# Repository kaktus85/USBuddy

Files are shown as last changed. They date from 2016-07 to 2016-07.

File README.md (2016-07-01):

# USBuddy
This repository contains all the available documentation and source files for USBuddy USB development tool project.
- A copy of this is also available on Google Drive: https://drive.google.com/drive/folders/0B7G3xJXZNLUpYzR0Vlo4bV9fNGM
- An article about this project is here: http://kaktuscircuits.blogspot.cz/2016/03/usbuddy.html and on Hackaday.io: https://hackaday.io/project/10372-usbuddy
- USBuddy can be purchased through Tindie: https://www.tindie.com/products/Kaktus/usbuddy-usb-development-tool/

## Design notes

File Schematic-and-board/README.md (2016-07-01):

# Schematic and Board
- Cadsoft Eagle source files for the PCB of USBuddy.
- A PNG schematic also included for a quick reference without having to install Eagle.
- Pinout of USBuddy header for quick reference in PNG file.

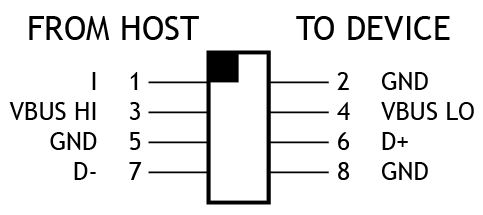
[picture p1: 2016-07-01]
Schematic-and-board/USBuddy pinout.png

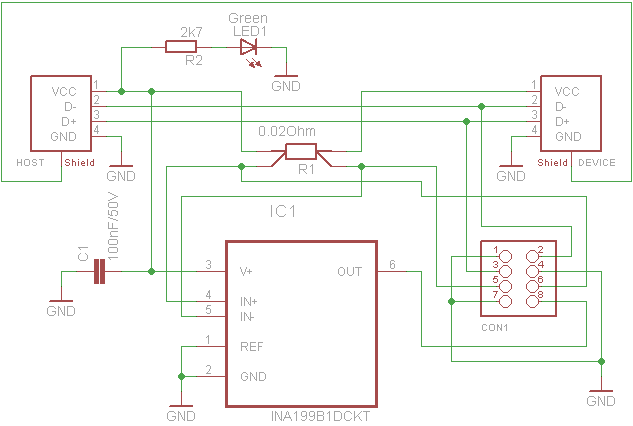
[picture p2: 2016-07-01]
Schematic-and-board/usbuddy.png

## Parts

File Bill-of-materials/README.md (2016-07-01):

# Bill of Materials
The list of items for the construction of USBuddy.

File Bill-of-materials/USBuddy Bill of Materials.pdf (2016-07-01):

Printed circuit board

Symbol in schematic | Description | Value | Package
C1 | MLCC X7R | 100nF/50V | 0603
CON1 | 2×4 SMT pin header | | 2.54mm pitch
DEVICE | USB 2.0 A connector | UBA-4R-S14HD-4S
HOST | USB 2.0 B connector | TE connectivity 1-1734346-1
IC1 | INA199B1DCKT | | SC70
LED1 | Green | 20 mA | 0603
R1 | Current shunt resistor, Kelvin connection | 0R02 | 1206-4wire
R2 | Resistor 250 mW | 2k7 | 1206

## USBuddy 1.0 – Bill of Materials

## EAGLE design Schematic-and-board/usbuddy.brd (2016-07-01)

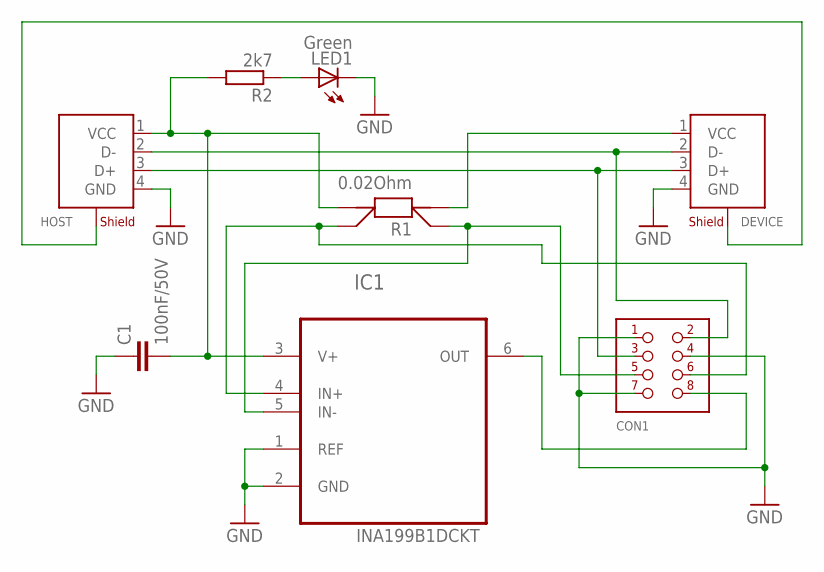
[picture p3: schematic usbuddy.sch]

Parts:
C1: 100nF/50V; C0603K
CON1: PINHEAD-02X04-SMT-2.54; 2X04-SMT-PINHEAD
DEVICE: USB-A-SMT; USB-A-SMT-UBA-4R-S14HD-4S
HOST: USB-B-SMT
IC1: INA199A2DCKR; SOT65P210X110-6N; MPN INA199B1DCKT
LED1: Green; CHIP-LED0603
R1: 0.02Ohm; 1206-4WIRE
R2: 2k7; R1206

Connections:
D+: CON1.3, DEVICE.3 (D+), HOST.3 (D+)
D-: CON1.2, DEVICE.2 (D-), HOST.2 (D-)
GND: C1.1, CON1.1, CON1.4, CON1.7, DEVICE.4 (GND), HOST.4 (GND), IC1.1 (REF), IC1.2 (GND), LED1.C
unnamed: CON1.5, IC1.5 (IN-), R1.V1
unnamed: CON1.8, IC1.6 (OUT)
unnamed: DEVICE.1 (VCC), R1.I1
unnamed: CON1.6, IC1.4 (IN+), R1.V2
unnamed: LED1.A, R2.1
SHIELD: DEVICE.S1 (SHIELD), DEVICE.S2 (SHIELD), DEVICE.S3 (SHIELD), DEVICE.S4 (SHIELD), HOST.S1 (SHIELD), HOST.S2 (SHIELD)
VBUS: C1.2, HOST.1 (VCC), IC1.3 (V+), R1.I2, R2.2

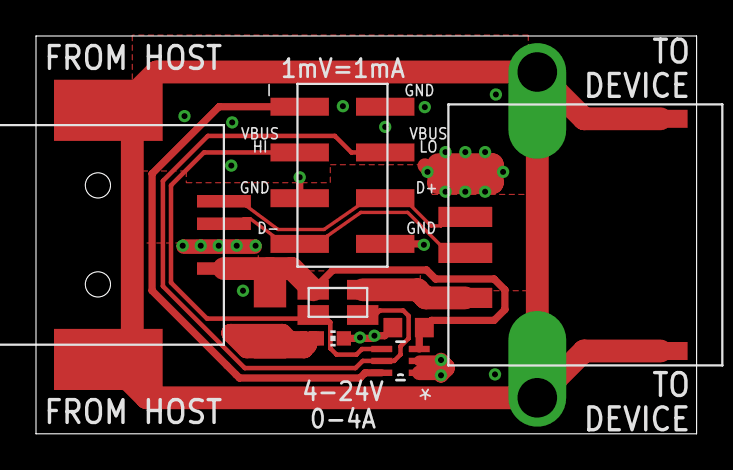
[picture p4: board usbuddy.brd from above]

Board: 2 copper layers, 36.7 x 22.1 mm, 8 parts (0 on the bottom side), 10 nets.

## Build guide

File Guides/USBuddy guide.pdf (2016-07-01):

## Detailed guide for using your USBuddy

Board revision: 1.0
Guide revision: A (2016-03-18)

### Introduction

USBuddy is a tool for monitoring and developing USB 2.0 devices and chargers. USBuddy breaks out all signals from USB 2.0 and measures the current using a small, 20 mΩ shunt resistor which has negligible impact on bus voltage. At full 0.5 A, the voltage drop is an insignificant 10 mV. The voltage drop is amplified by a factor of 50 to give a convenient ratio

### 1 mV = 1 mA. USBuddy is rated for 24 V and 4 A so you can develop powerful USB chargers

too. USBuddy also contains a green LED diode which indicates the presence of voltage on the bus.

### Specifications

Parameter | Min | Typical | Max | Unit
Bus voltage | 4 | | 24 | V
Current | 0 | | 4 | A
Current measurement error (at 100 mA) | | ±0.5% | ±2%
LED current (VBUS = 5 V) | | 1.2 | | mA

### How to use USBuddy

1) Using a USB A-B cable, connect your host (such as computer) to the “FROM HOST” port. The LED should light green.
2) Connect your device to the “TO DEVICE” port.
3) Access bus voltage, current and differential data lines on the pin header.
4) You can measure bus voltage either on VBUS HI or VBUS LO, the difference is insignificant. The voltage the device sees is more close to VBUS LO though.
5) If you wish to measure the current using your own amplifier, measure the voltage difference between VBUS HI and VBUS LO. The resistance is 20 mΩ.

### Pin header mapping

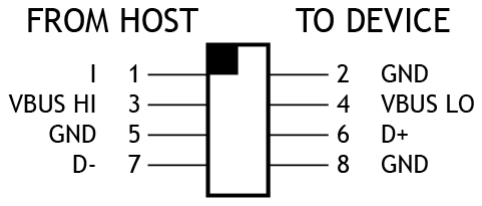
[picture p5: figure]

Number | Label | Description
1 | I | Device current from the internal amplifier, 1 mV = 1 mA, measure against GND.
2 | GND | Ground.
3 | VBUS HI | Bus voltage on the host side (before the current shunt).
4 | VBUS LO | Bus voltage on the device side (after the current shunt).
5 | GND | Ground.
6 | D+ | Positive signal of the differential data pair.
7 | D- | Negative signal of the differential data pair.
8 | GND | Ground.
